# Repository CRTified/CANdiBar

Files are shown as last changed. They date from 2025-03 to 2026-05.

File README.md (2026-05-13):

# CANdiBar

## IMPORTANT

This project is very experimental. While it works *for me* in my Voron V0.2, do not assume that it
works for you. Proceed at your own risk.

## Pictures

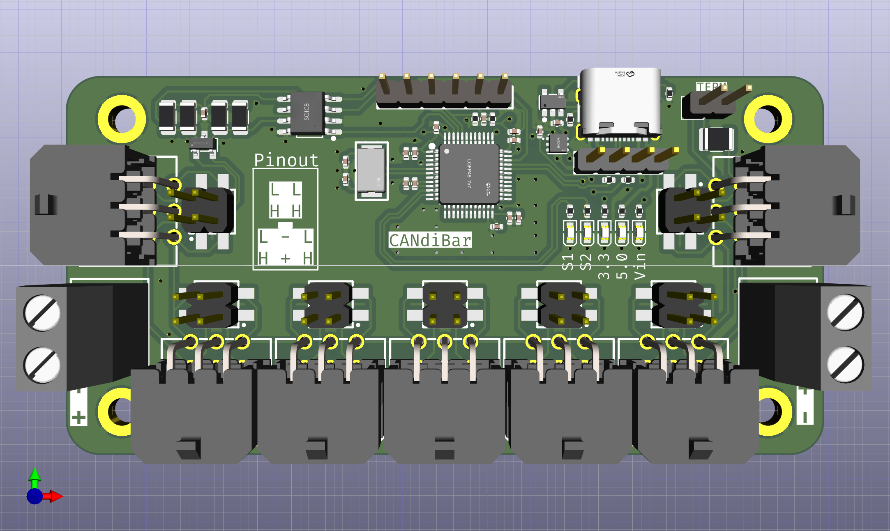
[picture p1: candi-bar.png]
The front view of the CANdIBar PCB

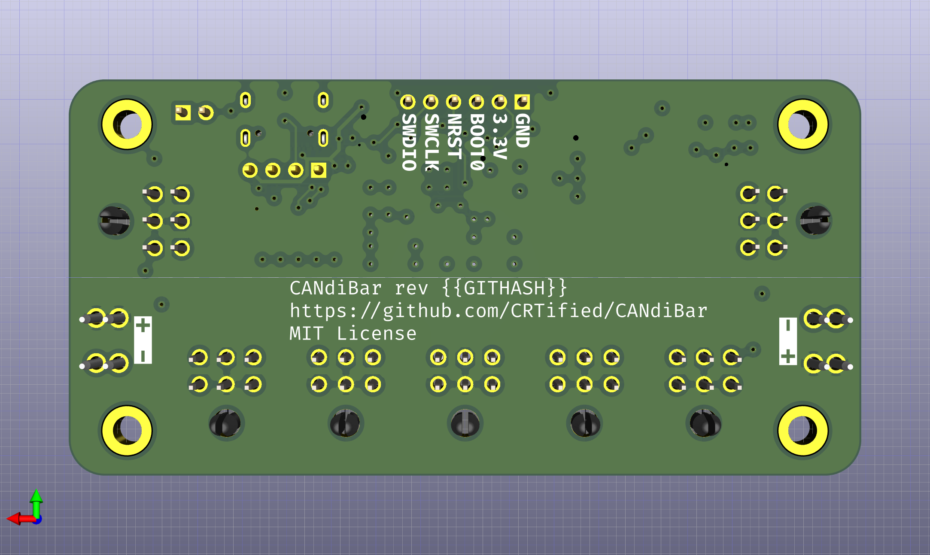
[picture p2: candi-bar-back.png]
The back view of the CANdIBar PCB

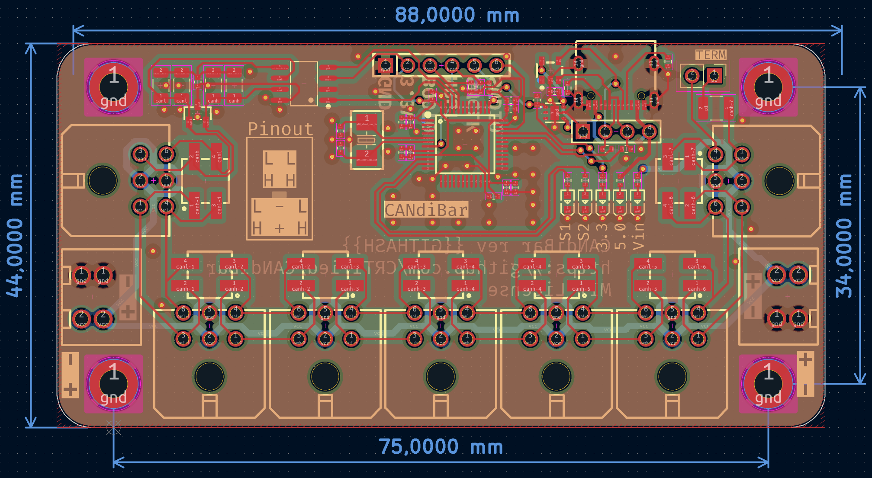
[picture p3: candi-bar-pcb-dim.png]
A screenshot of the dimensions and PCB editor CANdIBar PCB


## What is this?

This repository aims to contain a small CAN bus and power distribution
board. However, I wanted to avoid making all devices connected by a stub.

Properties:

 - Seven ports for a 2x3P Molex MicroFit 3.0
 - USB2CAN adapter compatible with candlelight
 - Proper CAN setup (No star topology that makes everythin a stub)
 - Pass-through connection configurable by jumper
 - Termination on last slot (might require pass-through on multiple ports)

## Why?

I wanted to try [atopile](https://atopile.io/) and a simple
distribution board seemed like a great fit to test the whole design
process.

I also wanted to have a sane piece of hardware for simplifying the
wiring in my 3D printer, as the
[Voron v0.2r1](https://vorondesign.com/voron0.2) gets pretty crowded
when using more than two MCUs.

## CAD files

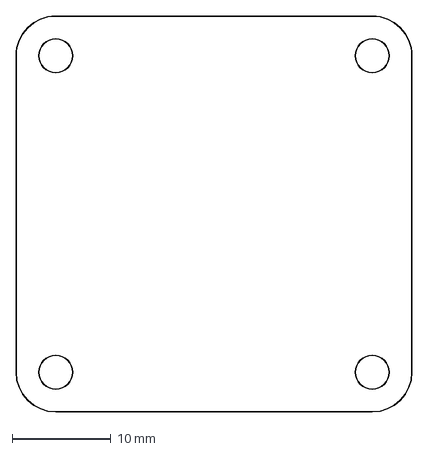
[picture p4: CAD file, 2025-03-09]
elec/src/sn65hvd230dr/mech/template_40x40.dxf
40.0 x 40.0 mm

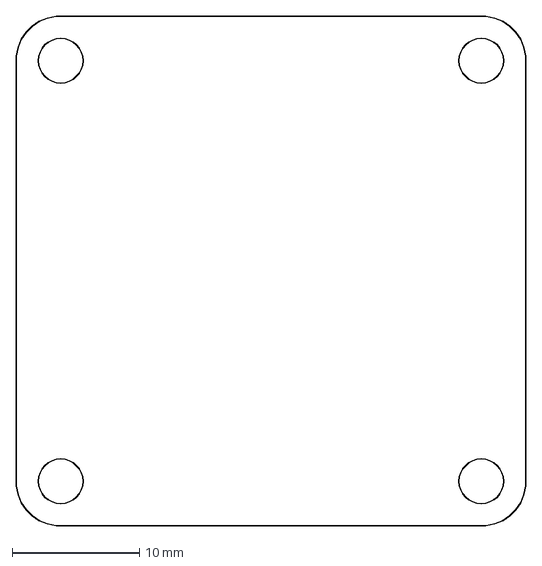
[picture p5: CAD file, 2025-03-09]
elec/src/sn65hvd230dr/mech/template_outline.dxf
40.0 x 40.0 mm

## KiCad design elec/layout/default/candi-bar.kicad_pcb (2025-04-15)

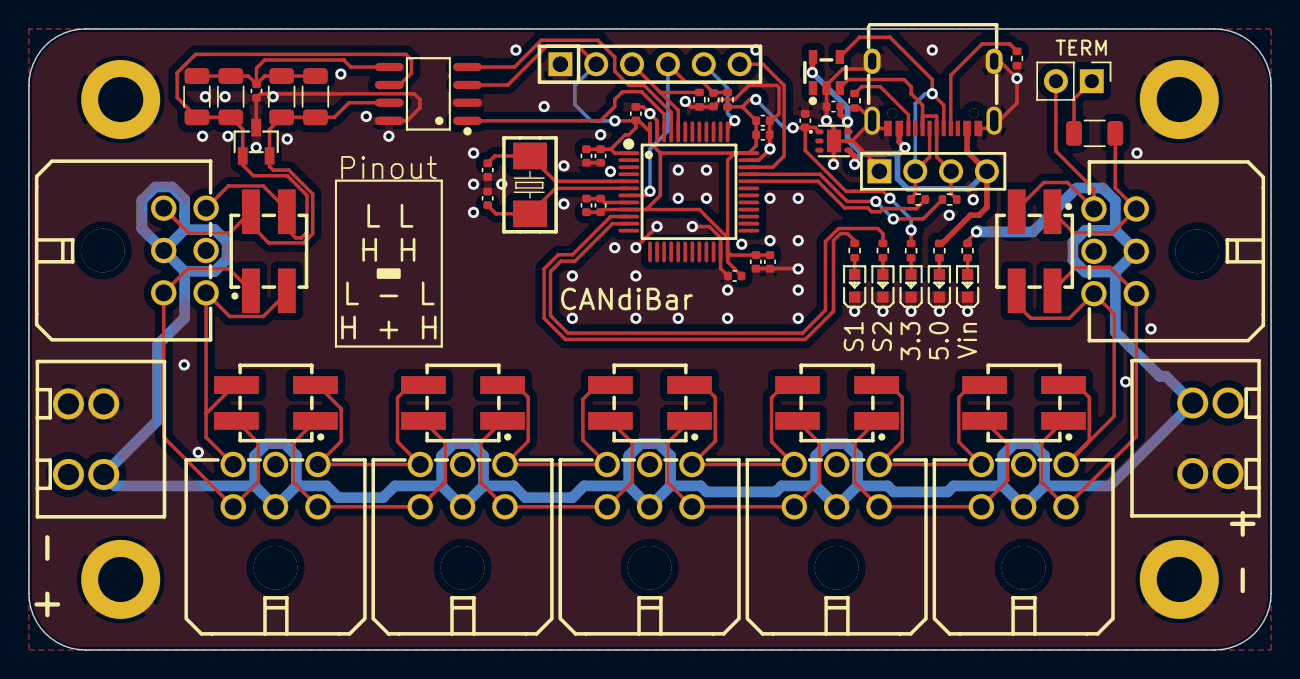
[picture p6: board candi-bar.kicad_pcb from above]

Board: 4 copper layers, 88.0 x 44.0 mm, 67 parts (0 on the bottom side), 43 nets.

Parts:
C1, C2: 25V 1uF X5R ±10% 0402 Multilayer Ceramic Capacito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; C0402
C3, C4, C5: 10V 4.7uF X5R ±20% 0402 Multilayer Ceramic Capaci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; C0402
C6, C7, C8, C9, C10, C11, C13, C16: 16V 100nF X7R ±10% 0402 Multilayer Ceramic Capaci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; C0402
C12: 50V 4.7nF X7R ±10% 0402 Multilayer Ceramic Capaci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; C0402
C14, C15: 50V 22pF C0G ±5% 0402 Multilayer Ceramic Capacito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; C0402
J1, J2, J3, J4, J5, J6, J7: ?; CONN-TH_43045-0600
JP1, JP2, JP3, JP4, JP5, JP6, JP7: ?; HDR-SMD_4P-P2.54-V-M-R2-C2-LS7.5
JP8: ?; PinHeader_1x02_P2.54mm_Vertical
R1, R2: 62.5mW Thick Film Resistors 50V ±100ppm/℃ ±1% 5.1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; R0402
R3: 62.5mW Thick Film Resistors 50V ±100ppm/℃ ±1% 1kΩ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; R0402
R4, R6, R15: 62.5mW Thick Film Resistors 50V ±100ppm/℃ ±1% 10k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; R0402
R5, R13, R14: 62.5mW Thick Film Resistors 50V ±100ppm/℃ ±1% 510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; R0402
R7, R8, R9, R10, R16: 250mW Thick Film Resistors 200V ±100ppm/℃ ±1% 120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; R1206
R11, R12: 62.5mW Thick Film Resistors 50V ±1% ±100ppm/℃ 22Ω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; R0402
U1, U2, U3, U4: ?; MountingHole_3.2mm_M3_DIN965_Pad
U5, U6: ?; CONN-TH_978-Y-02
U7: ?; USB-C-SMD_TYPE-C-6PIN-2MD-073
U8: ?; SOT-23-5_L2.9-W1.6-P0.95-LS2.8-BR
U9: ?; HDR-TH_4P-P2.54-V-M-1
U10, U11, U12, U19, U20: ?; LED0603-RD
U13: ?; WSON-6_L2.0-W2.0-P0.65-TL-EP
U14: ?; LQFP-48_L7.0-W7.0-P0.50-LS9.0-BL
U15: ?; HDR-TH_6P-P2.54-V-M-A
U16: ?; SOIC-8_L4.9-W3.9-P1.27-LS6.0-BL
U17: ?; SOT-23-3_L2.9-W1.3-P1.90-LS2.4-BR
U18: ?; CRYSTAL-SMD_L5.0-W3.2

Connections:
boot0: R6.1, U14.44, U15.3
candi_u2c.can_trx.ic-vcc: C12.1, R7.2, R8.2, R9.2, R10.2, U16.5
candi_u2c.status_1.LED-a: R13.1, U19.2
candi_u2c.status_2.LED-a: R14.1, U20.2
canh: J1.3, JP1.2, R7.1, R8.1, U16.7, U17.2
canh-1: J1.1, J2.3, JP1.1, JP2.2
canh-2: J2.1, J3.3, JP2.1, JP3.2
canh-3: J3.1, J4.3, JP3.1, JP4.2
canh-4: J4.1, J5.3, JP4.1, JP5.2
canh-5: J5.1, J6.3, JP5.1, JP6.2
canh-6: J6.1, J7.3, JP6.1, JP7.2
canh-7: J7.1, JP7.1, R16.1
canl: J1.6, JP1.4, R9.1, R10.1, U16.6, U17.1
canl-1: J1.4, J2.6, JP1.3, JP2.4
canl-2: J2.4, J3.6, JP2.3, JP3.4
canl-3: J3.4, J4.6, JP3.3, JP4.4
canl-4: J4.4, J5.6, JP4.3, JP5.4
canl-5: J5.4, J6.6, JP5.3, JP6.4
canl-6: J6.4, J7.6, JP6.3, JP7.4
canl-7: J7.4, JP7.3, JP8.2
cc1: R1.1, U7.4
cc2: R2.1, U7.10
dm: R12.2, U7.5, U7.7, U8.4, U9.2
dp: R11.2, U7.6, U7.8, U8.3, U9.3
gnd: C1.2, C2.2, C3.2, C4.2, C5.2, C6.2, C7.2, C8.2, C9.2, C10.2, C11.2, C12.2, C13.2, C14.1, C15.1, C16.2, J1.5, J2.5, J3.5, J4.5, J5.5, J6.5, J7.5, R1.2, R2.2, R6.2, U1.1, U2.1, U3.1, U4.1, U5.1, U6.1, U7.1, U7.12, U7.13, U7.14, U8.2, U9.1, U10.1, U11.1, U12.1, U13.5, U13.7, U14.8, U14.23, U14.35, U14.47, U15.1, U16.2, U16.8, U17.3, U19.1, U20.1
nrst: C16.1, R15.1, U14.7, U15.4
p1: JP8.1, R16.2
pa0: R13.2, U14.10
pa1: R14.2, U14.11
pa11: R12.1, U14.32
pa12: R11.1, U14.33
pb8: U14.45, U16.4
pb9: U14.46, U16.1
pf0_slash_osc_in: C14.2, U14.5, U18.1
pf1_slash_osc_out: C15.2, U14.6, U18.2
pwr_3_3_status.LED-a: R5.1, U12.2
status_main.LED-a: R4.1, U11.2
swclk: U14.37, U15.5
swdio: U14.34, U15.6
usb_j1-vcc: C1.1, R3.2, U7.2, U7.11, U8.5, U9.4, U13.4, U13.6
usb_status.LED-a: R3.1, U10.2
vcc: J1.2, J2.2, J3.2, J4.2, J5.2, J6.2, J7.2, R4.2, U5.2, U6.2
vcc-1: C2.1, C3.1, C4.1, C5.1, C6.1, C7.1, C8.1, C9.1, C10.1, C11.1, C13.1, R5.2, R15.2, U13.1, U14.1, U14.9, U14.24, U14.36, U14.48, U15.2, U16.3

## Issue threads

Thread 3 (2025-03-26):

Switch to 4 layer board

CRTified, 2025-03-26:
Not much more expensive, but it allows proper power planes for distribution.

CRTified, 2025-04-05:
Done, using a Signal/GND/GND/Vcc Stack

Closed 2025-04-05.

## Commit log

2025-03-09 feat: Initialized ato project
    [candi-bar.kicad_pcb, candi-bar.kicad_sch, template_40x40.dxf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]
2025-03-09 feat: Initial attempt of CAN Hub
    [candi-bar.kicad_pcb]
2025-03-09 feat: First revision of the CAN bus
    [candi-bar.kicad_pcb]
2025-03-11 feat(pcb): Minor Touchup
    [candi-bar.kicad_pcb]
2025-03-19 feat: Add additional u2c circutry
    [candi-bar.kicad_pcb, sn65hvd230dr.kicad_pcb, sn65hvd230dr.kicad_sch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]
2025-03-31 feat: Add u2c and pcb
    [candi-bar.kicad_pcb]
2025-03-31 chore(deps): update flake.lock
    Flake lock file updates:
    • Updated input 'nixpkgs':
    'github:NixOS/nixpkgs/36fd87baa9083f34f7f5027900b62ee6d09b1f2f?narHash=sha256-Wh7esNh7G24qYleLvgOSY/7HlDUzWaL/n4qzlBePpiw%3D' (2025-03-07)
    → 'github:NixOS/nixpkgs/52faf482a3889b7619003c0daec593a1912fddc1?narHash=sha256-6hl6L/tRnwubHcA4pfUUtk542wn2Om%2BD4UnDhlDW9BE%3D' (2025-03-30)
    • Updated input 'pre-commit-hooks':
    'github:cachix/git-hooks.nix/b5a62751225b2f62ff3147d0a334055ebadcd5cc?narHash=sha256-srpAbmJapkaqGRE3ytf3bj4XshspVR5964OX5LfjDWc%3D' (2025-03-07)
    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
2025-04-02 feat: Semifinal design
    [candi-bar.kicad_pcb]
2025-04-02 feat: Reworked with SMD Jumpering
    [candi-bar.kicad_pcb]
2025-04-02 fix: Make silkscreen less ambigous
    [candi-bar.kicad_pcb]
2025-04-02 docs: Add picture of PCB designer
2025-04-04 feat: Remove silkscreens
    [candi-bar.kicad_pcb]
2025-04-05 chore(deps): update flake.lock
    'github:NixOS/nixpkgs/52faf482a3889b7619003c0daec593a1912fddc1?narHash=sha256-6hl6L/tRnwubHcA4pfUUtk542wn2Om%2BD4UnDhlDW9BE%3D' (2025-03-30)
    → 'github:NixOS/nixpkgs/2c8d3f48d33929642c1c12cd243df4cc7d2ce434?narHash=sha256-F7n4%2BKOIfWrwoQjXrL2wD9RhFYLs2/GGe/MQY1sSdlE%3D' (2025-04-02)
    • Updated input 'nixpkgs-ato':
    'github:CRTified/nixpkgs/f6a709dc03258fcdee09f4a7a86cacf407627916?narHash=sha256-3gPHHv/2VDrhV3NnxyIPG2jfqpOaF%2BgaEAo3e01hCms%3D' (2025-04-05)
    → 'github:CRTified/nixpkgs/134d39b71414f549e494006e164f352bfc35629f?narHash=sha256-OE%2B%2Bet1lwwfq1BsR9LVB/ENqNpY4YeCcDf6FeL%2BZWfw%3D'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
2025-04-05 chore(deps): update flake.lock
    'github:CRTified/nixpkgs/134d39b71414f549e494006e164f352bfc35629f?narHash=sha256-OE%2B%2Bet1lwwfq1BsR9LVB/ENqNpY4YeCcDf6FeL%2BZWfw%3D' (2025-04-05)
    → 'github:CRTified/nixpkgs/9ba0ef597ee012bd23c33773216bd1527d1533aa?narHash=sha256-%2BrU%2BXsC9RbvRIRW62h25Sm3JDKZcjetOLmNJ%2B65o8a4%3D' (2025-04-05)
    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
2025-04-05 chore: Switch to ato v3
    [candi-bar.kicad_pcb]
2025-04-05 fix: Re-add template for GITHASH
    [candi-bar.kicad_pcb]
2025-04-06 feat: Allow larger tolerance of status led current
    [candi-bar.kicad_pcb]
2025-04-06 chore: Pin CI to specific version of atopile
2025-04-06 feat: Switch to other screw terminal for power
    [candi-bar.kicad_pcb]
2025-04-15 fix: Switch to bigger termination resistors to be able to handle a fault
    [candi-bar.kicad_pcb]
2025-04-15 docs: Update pictures
    [candi-bar.kicad_pcb]
2025-04-15 fix: Change silkscreen on left power input
    [candi-bar.kicad_pcb]
2025-04-15 feat: Switch termination resistor to 1206 to use basic part
    [candi-bar.kicad_pcb]

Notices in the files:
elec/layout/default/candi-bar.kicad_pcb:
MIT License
